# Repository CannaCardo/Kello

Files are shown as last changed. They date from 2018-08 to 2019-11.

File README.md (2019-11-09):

# Kello
> A simple USB powered Nixie Clock




USB powered clock made on four classic Z567M Nixie tubes. Pretty simplistic, without unnecessary gadgets: displays time, can be set up both from PC app or via optional capacitive buttons. Refresh frequency, brightness, time format, time and date (for adjusting winter/ summer time) can be configured as needed. Settings and current time are stored in EEprom and RTC. If the clock is connected to the PC it will update its time every minute (using the provided link).

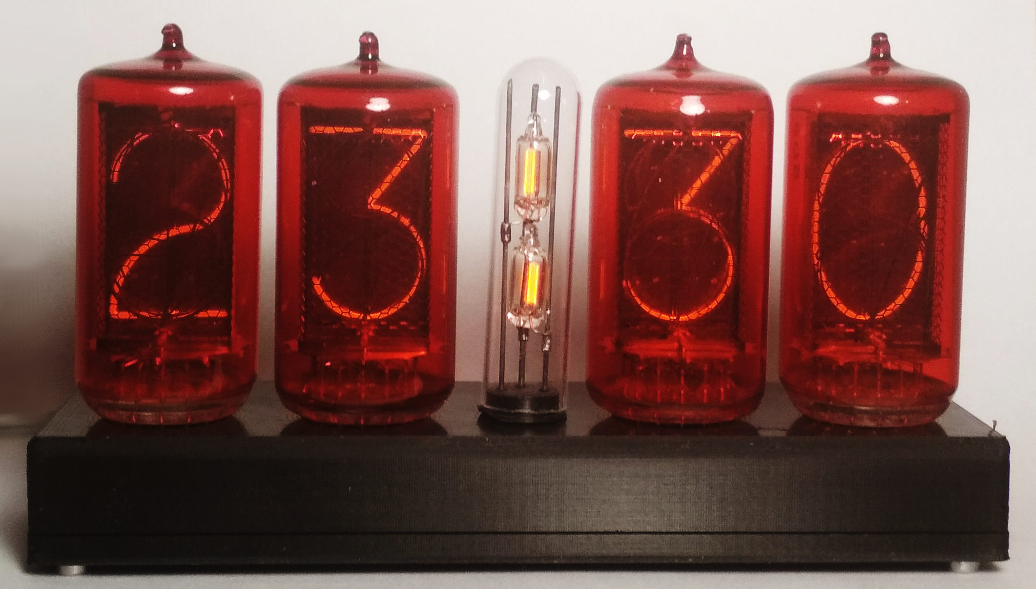
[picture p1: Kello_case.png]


For the prototype version I've dropped the idea of capacitive buttons integrated into the case, as the clock will stay connected to the PC and it's much more ergonomic to use the app.
The first idea for the clock opted for bluetooth/wifi integration, so that a smartphone could be used as interface for quick setup and the clock itself could synchronize time via Internet.  Since there already is a USB socket used to power the device it seemed silly not to connect it to the PC, which itself simplified the project rendering Wifi and BT pointless. 

## Construction advices

The Nixie standoffs can be made from D-Sub connectors (such as MH CONNECTORS MHDD25-F-T-B-M). They are pricey, but work wonders and look good. For this clock i used 3 connectors, and ended up with some leftover pins. To extract them from the socket itself cut the metal enclosure to release the black plastic holding the pins.

The dots (Neon bulbs) are soldered on 3 pieces of 2mm piano wire. Sanding the wire down before soldering will ease the process. 




## Release History

* 0.1.0
    * First Prototype
* 0.1.1
    * Placed GND Pour keepout under L1
    * Fixed RTC reseting at powerup

## Meta

Krzysztof Belewicz – belewicz@gmail.com

Distributed under the Beerware license. If you decide to build your own feel free to send me a pic.

[https://github.com/CannaCardo/github-link](https://github.com/CannaCardo/)

<!-- Markdown link & img dfn's -->
[Ver-image]: https://img.shields.io/badge/Version-1.0-orange.svg?longCache=true&style=flat-square
[Stat-image]: https://img.shields.io/badge/Status-Finished-green.svg?longCache=true&style=flat-square
[wiki]: https://github.com/CannaCardo/Kello/wiki

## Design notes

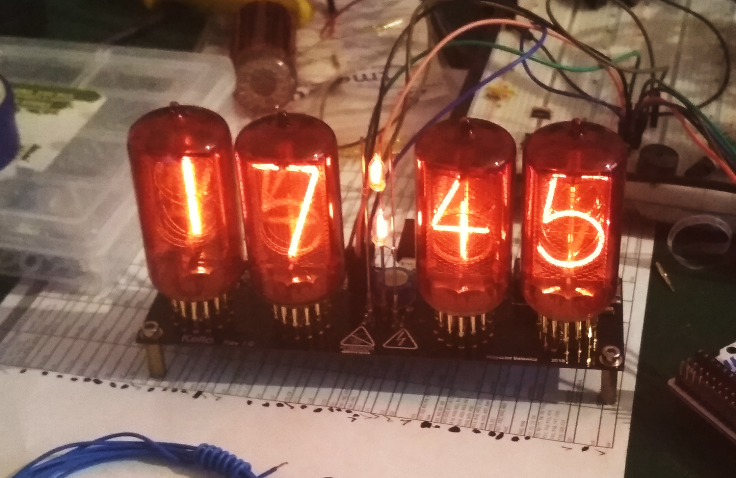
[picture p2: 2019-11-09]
Kello_bare.png

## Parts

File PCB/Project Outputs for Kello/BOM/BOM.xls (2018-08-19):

Designator | Comment | Value | Tolerance | MaxVoltage | Quantity | Supplier 1 | Supplier Part Number 1 | Manufacturer 1 | Manufacturer Part Number 1
V1, V2, V3, V4 | Z566M Nixie Tube |  |  |  | 4
C30, C31, C32, C33, P2, R47, SCR1, SCR2, SCR3, SCR4, SPCR1, SPCR2, SPCR3, SPCR4 | Capacitor, Header 1x5, Resistor, M3 Screw, M3 Spacer | DNP, [NoParam], NC | [NoValue], [NoParam], 1% |  | 14
C2 | Capacitor | 470n | 10% | 10V | 1 | Farnell | 2524844 (https://octopart-clicks.com/click/altium?sku=2524844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) | WALSIN (https://octopart-clicks.com/click/altium?sku=2524844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) | 0603B474K100CT (https://octopart-clicks.com/click/altium?sku=2524844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)
C16, C18 | Capacitor | 100u | 20% | 10V | 2 | Farnell | 2525204 (https://octopart-clicks.com/click/altium?sku=2525204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) | TDK (https://octopart-clicks.com/click/altium?sku=2525204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) | C4532X5R1A107M280KC (https://octopart-clicks.com/click/altium?sku=2525204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)
C19 | Capacitor | 100p | 5% | 250V | 1 | Farnell | 2812519 (https://octopart-clicks.com/click/altium?sku=2812519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) | WURTH ELEKTRONIK (https://octopart-clicks.com/click/altium?sku=2812519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) | 885342006003 (https://octopart-clicks.com/click/altium?sku=2812519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)
C20, C21 | Capacitor | 1u | 10% | 250V | 2 | Farnell | 2435499 (https://octopart-clicks.com/click/altium?sku=2435499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) | TDK (https://octopart-clicks.com/click/altium?sku=2435499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) | CGA8P3X7T2E105K250KA (https://octopart-clicks.com/click/altium?sku=2435499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)
C22, C23 | Capacitor | 100n | 10% | 250V | 2 | Farnell | 2852360 (https://octopart-clicks.com/click/altium?sku=2852360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) | KEMET (https://octopart-clicks.com/click/altium?sku=2852360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) | C1206C104KARECAUTO (https://octopart-clicks.com/click/altium?sku=2852360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)
C24 | Capacitor | 560p | 5% | 250V | 1 | Farnell | 2810275 (https://octopart-clicks.com/click/altium?sku=2810275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) | KEMET (https://octopart-clicks.com/click/altium?sku=2810275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) | C0603C561JAGACAUTO (https://octopart-clicks.com/click/altium?sku=2810275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)
C26 | Capacitor | 430p | 5% | 50V | 1 | Farnell | 2821196 (https://octopart-clicks.com/click/altium?sku=2821196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) | KEMET (https://octopart-clicks.com/click/altium?sku=2821196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) | C0603C431J5GACTU (https://octopart-clicks.com/click/altium?sku=2821196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)
C27 | Capacitor | 47u | 20% | 16V | 1 | Farnell | 1838761 (https://octopart-clicks.com/click/altium?sku=1838761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) | KEMET (https://octopart-clicks.com/click/altium?sku=1838761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) | C1210C476M4PACTU (https://octopart-clicks.com/click/altium?sku=1838761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)
D1, D3 | BAT54 |  |  |  | 2 | Farnell | 2322476
L1 | 7447709330 | 33uH | 20% |  | 1 | Farnell | 2082654 (https://octopart-clicks.com/click/altium?sku=2082654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) | WURTH ELEKTRONIK (https://octopart-clicks.com/click/altium?sku=2082654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) | 7447709330 (https://octopart-clicks.com/click/altium?sku=2082654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)
R38 | Resistor | 634k | 1% |  | 1 | Farnell | 2139670 (https://octopart-clicks.com/click/altium?sku=2139670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) | VISHAY (https://octopart-clicks.com/click/altium?sku=2139670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) | CRCW1206634KFKEA. (https://octopart-clicks.com/click/altium?sku=2139670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)
R39 | Resistor | 4.12k | 1% |  | 1 | Farnell | 1652883 (https://octopart-clicks.com/click/altium?sku=1652883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) | VISHAY (https://octopart-clicks.com/click/altium?sku=1652883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) | CRCW06034K12FKEA (https://octopart-clicks.com/click/altium?sku=1652883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)
R40 | Resistor | 7.68k | 1% |  | 1 | Farnell | 2307849 (https://octopart-clicks.com/click/altium?sku=2307849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) | PANASONIC (https://octopart-clicks.com/click/altium?sku=2307849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) | ERJ8ENF7681V (https://octopart-clicks.com/click/altium?sku=2307849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)
R41 | Resistor | 60.4k | 1% |  | 1 | Farnell | 2138476 (https://octopart-clicks.com/click/altium?sku=2138476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) | VISHAY (https://octopart-clicks.com/click/altium?sku=2138476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) | CRCW060360K4FKEA. (https://octopart-clicks.com/click/altium?sku=2138476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)
R46 | Resistor | 0.1 | 1% |  | 1 | Farnell | 1099914 (https://octopart-clicks.com/click/altium?sku=1099914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) | WELWYN (https://octopart-clicks.com/click/altium?sku=1099914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) | LR1206-R10FW (https://octopart-clicks.com/click/altium?sku=1099914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)
U2 | ECMF02-4CMX8 |  |  |  | 1 | Farnell | 2629721
U5 | UCC3803 |  |  |  | 1 | Farnell | 2323690 (https://octopart-clicks.com/click/altium?sku=2323690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) | TEXAS INSTRUMENTS (https://octopart-clicks.com/click/altium?sku=2323690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) | UCC3803D (https://octopart-clicks.com/click/altium?sku=2323690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)
C1, C3, C7, C9, C10, C12, C13, C14, C15, C17, C25 | Capacitor | 100n | -20/+80% | 25V | 11 | TME | CL10F104ZA8NNNC (https://octopart-clicks.com/click/altium?sku=CL10F104ZA8NNNC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) | SAMSUNG (https://octopart-clicks.com/click/altium?sku=CL10F104ZA8NNNC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) | CL10F104ZA8NNNC (https://octopart-clicks.com/click/altium?sku=CL10F104ZA8NNNC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)
C4 | Capacitor | 47n | 10% | 16V | 1 | TME | VJ0603Y473KXJCW1BC (https://octopart-clicks.com/click/altium?sku=VJ0603Y473KXJCW1BC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) | VISHAY (https://octopart-clicks.com/click/altium?sku=VJ0603Y473KXJCW1BC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) | VJ0603Y473KXJCW1BC (https://octopart-clicks.com/click/altium?sku=VJ0603Y473KXJCW1BC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)
C5 | Capacitor | 10u | 20% | 6.3V | 1 | TME | GRM188R60J106ME47D (https://octopart-clicks.com/click/altium?sku=GRM188R60J106ME47D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) | MURATA (https://octopart-clicks.com/click/altium?sku=GRM188R60J106ME47D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) | GRM188R60J106ME47D (https://octopart-clicks.com/click/altium?sku=GRM188R60J106ME47D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)
C6, C8 | Capacitor | 1u | 10% | 25V | 2 | TME | GCM188R71E105KA64D (https://octopart-clicks.com/click/altium?sku=GCM188R71E105KA64D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) | MURATA (https://octopart-clicks.com/click/altium?sku=GCM188R71E105KA64D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) | GCM188R71E105KA64D (https://octopart-clicks.com/click/altium?sku=GCM188R71E105KA64D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)
C11 | 0.47F | 0.47F |  |  | 1 | TME | FGH0V474ZF (https://octopart-clicks.com/click/altium?sku=FGH0V474ZF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) | KEMET (https://octopart-clicks.com/click/altium?sku=FGH0V474ZF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) | FGH0V474ZF (https://octopart-clicks.com/click/altium?sku=FGH0V474ZF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)
C28 | Capacitor | 1n | 10% | 50V | 1 | TME | VJ0603Y102KXACW1BC (https://octopart-clicks.com/click/altium?sku=VJ0603Y102KXACW1BC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) | VISHAY (https://octopart-clicks.com/click/altium?sku=VJ0603Y102KXACW1BC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) | VJ0603Y102KXACW1BC (https://octopart-clicks.com/click/altium?sku=VJ0603Y102KXACW1BC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)
C29 | Capacitor | 220p | 10% | 50V | 1 | TME | VJ0603Y221KXACW1BC (https://octopart-clicks.com/click/altium?sku=VJ0603Y221KXACW1BC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) | VISHAY (https://octopart-clicks.com/click/altium?sku=VJ0603Y221KXACW1BC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) | VJ0603Y221KXACW1BC (https://octopart-clicks.com/click/altium?sku=VJ0603Y221KXACW1BC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)
D2 | ES1D |  |  |  | 1 | TME | ES1D
FB1, FB2, FB3 | Ferrite Bead | 120@100MHz |  |  | 3 | TME | BLM18KG121TN1D
FB4, FB5 | Ferrite Bead | 60@100MHz |  |  | 2 | TME | BLM18BB600SN1D (https://octopart-clicks.com/click/altium?sku=BLM18BB600SN1D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) | MURATA (https://octopart-clicks.com/click/altium?sku=BLM18BB600SN1D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) | BLM18BB600SN1D (https://octopart-clicks.com/click/altium?sku=BLM18BB600SN1D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)
N1 | NEON |  |  |  | 1 | TME | NEON-9
P1 | MicroUSB-B |  |  |  | 1 | TME | MX-47346-0001 (https://octopart-clicks.com/click/altium?sku=MX-47346-0001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) | MOLEX (https://octopart-clicks.com/click/altium?sku=MX-47346-0001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) | 473460001 (https://octopart-clicks.com/click/altium?sku=MX-47346-0001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)
Q1 | Crystal 2 pin | 32.768 kHz |  |  | 1 | TME | IL3X2-HX5F12.5-32.768KHZ (https://octopart-clicks.com/click/altium?sku=IL3X2-HX5F12.5-32.768KHZ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) | ILSI (https://octopart-clicks.com/click/altium?sku=IL3X2-HX5F12.5-32.768KHZ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) | IL3X2-HX5F12.5-32.768KHZ (https://octopart-clicks.com/click/altium?sku=IL3X2-HX5F12.5-32.768KHZ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)
Q2 | 24Mhz | 24 Mhz |  |  | 1 | TME | 3225-24M-SR (https://octopart-clicks.com/click/altium?sku=3225-24M-SR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) | SR PASSIVES (https://octopart-clicks.com/click/altium?sku=3225-24M-SR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) | 3225-24M-SR (https://octopart-clicks.com/click/altium?sku=3225-24M-SR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)
Q3 | FDS2672 |  |  |  | 1 | TME | FDS2672 (https://octopart-clicks.com/click/altium?sku=FDS2672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) | ON SEMICONDUCTOR (FAIRCHILD) (https://octopart-clicks.com/click/altium?sku=FDS2672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) | FDS2672 (https://octopart-clicks.com/click/altium?sku=FDS2672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)
R1, R2, R3, R4, R36, R44 | Resistor | 100k | 1% |  | 6 | TME | CRCW0603100KFKEA (https://octopart-clicks.com/click/altium?sku=CRCW0603100KFKEA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) | VISHAY (https://octopart-clicks.com/click/altium?sku=CRCW0603100KFKEA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) | CRCW0603100KFKEA (https://octopart-clicks.com/click/altium?sku=CRCW0603100KFKEA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)
R5, R6, R7, R8 | Resistor | 430k | 1% |  | 4 | TME | SMD0603-430k
R9, R10, R11, R12, R17, R18, R19, R22, R23, R24, R25, R26, R27, R28, R29, R30 | Resistor | 33k | 1% |  | 16 | TME | SMD0603-33k
R13, R14, R15, R16, R34, R35, R37, R49 | Resistor | 2k | 1% |  | 8 | TME | SMD0603-2K-1% (https://octopart-clicks.com/click/altium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) | ROYAL OHM (https://octopart-clicks.com/click/altium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) | 0603SAF2001T5E (https://octopart-clicks.com/click/altium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)
R20, R21 | Resistor | 220k | 1% |  | 2 | TME | SMD0603-220k
R31, R32, R33, R43, R45 | Resistor | 1k | 1% |  | 5 | TME | SMD0603-1K-1% (https://octopart-clicks.com/click/altium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) | ROYAL OHM (https://octopart-clicks.com/click/altium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) | 0603SAF1001T5E (https://octopart-clicks.com/click/altium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)
R42, R48 | Resistor | 0 | 1% |  | 2 | TME | CRCW06030000Z0TABC (https://octopart-clicks.com/click/altium?sku=CRCW06030000Z0TABC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) | VISHAY (https://octopart-clicks.com/click/altium?sku=CRCW06030000Z0TABC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) | CRCW06030000Z0TABC (https://octopart-clicks.com/click/altium?sku=CRCW06030000Z0TABC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)
T1, T2, T3, T4 | MMBTA92 |  |  |  | 4 | TME | MMBTA92
T5, T6, T7, T8, T9, T10, T11, T12, T13, T14, T15, T16, T17, T18, T19, T20, T21 | MMBTA42 |  |  |  | 17 | TME | MMBTA42LT1G
U1 | STM32F042C6U6 |  |  |  | 1 | TME | STM32F042C6U6
U3 | LD1117AV33 |  |  |  | 1 | TME | LD1117AS33 (https://octopart-clicks.com/click/altium?sku=LD1117AS33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) | ST MICROELECTRONICS (https://octopart-clicks.com/click/altium?sku=LD1117AS33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) | LD1117AS33TR (https://octopart-clicks.com/click/altium?sku=LD1117AS33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)
U4 | AT24C04D |  |  |  | 1 | TME | AT24C04D-MAHM-T (https://octopart-clicks.com/click/altium?sku=AT24C04D-MAHM-T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) | MICROCHIP (https://octopart-clicks.com/click/altium?sku=AT24C04D-MAHM-T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) | AT24C04D-MAHM-T (https://octopart-clicks.com/click/altium?sku=AT24C04D-MAHM-T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)

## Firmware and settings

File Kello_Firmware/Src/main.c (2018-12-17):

/**
  ******************************************************************************
  * @file           : main.c
  * @brief          : Main program body
  ******************************************************************************
  * This notice applies to any and all portions of this file
  * that are not between comment pairs USER CODE BEGIN and
  * USER CODE END. Other portions of this file, whether 
  * inserted by the user or by software development tools
  * are owned by their respective copyright owners.
  *
  * Copyright (c) 2018 STMicroelectronics International N.V. 
  * All rights reserved.
  *
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
  ******************************************************************************
  */
/* Includes ------------------------------------------------------------------*/
#include "main.h"
#include "stm32l4xx_hal.h"
#include "usb_device.h"

/* USER CODE BEGIN Includes */
//#include "usbd_cdc_if.h" // USB
#include "EEprom.h"
#include "Display.h"
#include "Defines.h"
#include "USB.h"
/* USER CODE END Includes */

ADC_HandleTypeDef hadc1;

I2C_HandleTypeDef hi2c1;

RTC_HandleTypeDef hrtc;

TIM_HandleTypeDef htim1;
TIM_HandleTypeDef htim2;
DMA_HandleTypeDef hdma_tim2_ch3;
DMA_HandleTypeDef hdma_tim2_ch2_ch4;

/* USER CODE BEGIN PV */
HAL_StatusTypeDef DisplayStatus;
HAL_StatusTypeDef EEpromStatus;
/* USER CODE END PV */

void SystemClock_Config(void);
static void MX_GPIO_Init(void);
static void MX_DMA_Init(void);
static void MX_ADC1_Init(void);
static void MX_I2C1_Init(void);
static void MX_RTC_Init(void);
static void MX_TIM1_Init(void);
static void MX_TIM2_Init(void);

void HAL_TIM_MspPostInit(TIM_HandleTypeDef *htim);
                                

/* USER CODE BEGIN PFP */

/* USER CODE END PFP */

/**
  * @brief  The application entry point.
  *
  * @retval None
  */
int main(void)
{
  /* USER CODE BEGIN 1 */
  DisplayStatus = HAL_OK;
  EEpromStatus 	= HAL_OK;
  /* USER CODE END 1 */

  /* MCU Configuration----------------------------------------------------------*/

  /* Reset of all peripherals, Initializes the Flash interface and the Systick. */
  HAL_Init();

  /* Configure the system clock */
  SystemClock_Config();

  /* Initialize all configured peripherals */
  MX_GPIO_Init();
  MX_DMA_Init();
  MX_ADC1_Init();
  MX_I2C1_Init();
  MX_RTC_Init();
  MX_TIM1_Init();
  MX_TIM2_Init();
  MX_USB_DEVICE_Init();
  /* USER CODE BEGIN 2 */

  // Initialize settings
  EEpromStatus |= EEprom_Init();

  // Start HV Display
  DisplayStatus |= Display_Init( &htim1, &htim2 );
  Display_Set_Brightness( 	EEprom_Get_Brightness()  );
  Display_Set_RefreshRate( 	EEprom_Get_RefreshRate() );
  Display_Set_TimeFormat( 	EEprom_Get_TimeFormat()  );
  Display_Set_DotStyle(		EEprom_Get_DotStyle()	 );
  Display_Set_DotCustom( 	EEprom_Get_DotCustom() 	 );
  Display_Start();

  USB_Init();

  /* USER CODE END 2 */

  /* Infinite loop */
  /* USER CODE BEGIN WHILE */
  uint8_t OldSec = Display_Get_SL();
  while (1)
  {
  /* USER CODE END WHILE */

  /* USER CODE BEGIN 3 */
	  // React to incoming requests
	  if( USB_RX_IsReceived() ) USB_RX_Respond();

	  // Wait for a second
	  if( OldSec == Display_Get_SL() ) continue;
	  OldSec = Display_Get_SL();

	  //USB_TX_Info();
  }
  /* USER CODE END 3 */

}

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


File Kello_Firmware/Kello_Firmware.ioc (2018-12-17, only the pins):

Mcu.UserName=STM32L433CBUx
PA10.GPIO_Label=EE_SDA
PA10.Signal=I2C1_SDA
PA11.Signal=USB_DM
PA12.Signal=USB_DP
PA8.GPIO_Label=EE_WP
PA8.Signal=GPIO_Output
PA9.GPIO_Label=EE_SCL
PA9.Signal=I2C1_SCL
PB10.GPIO_Label=DOT_L
PB10.Signal=S_TIM2_CH3
PB11.GPIO_Label=DOT_H
PB11.Signal=S_TIM2_CH4
PB12.GPIO_Label=Anode_4
PB12.Signal=GPIO_Output
PB13.GPIO_Label=Anode_3
PB13.Signal=GPIO_Output
PB14.GPIO_Label=Anode_2
PB14.Signal=GPIO_Output
PB15.GPIO_Label=Anode_1
PB15.Signal=GPIO_Output
PB2.GPIO_Label=HV_Enable
PB2.Signal=GPIO_Output
PB5.GPIO_Label=Digit_8
PB5.Signal=GPIO_Output
PB6.GPIO_Label=Digit_7
PB6.Signal=GPIO_Output
PB7.GPIO_Label=Digit_6
PB7.Signal=GPIO_Output
PB8.GPIO_Label=Digit_4
PB8.Signal=GPIO_Output
PB9.GPIO_Label=Digit_2
PB9.Signal=GPIO_Output
PC13.GPIO_Label=Digit_3
PC13.Signal=GPIO_Output
PH3-BOOT0.GPIO_Label=Digit_5
PH3-BOOT0.Signal=GPIO_Output

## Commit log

2018-04-01 Schematics 1
    Added Nixie page (finished)
    Added Mechanical page
    Added uC page
    [Kello.PrjPCB, Kello_Mechanical.SchDoc, Kello_Nixie.SchDoc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]
2018-05-07 Finished schematic
    [Kello.PrjPCB, Kello_Mechanical.SchDoc, Kello_Nixie.SchDoc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]
2018-08-19 Prototype done
    -1.0 Prototype done
    -Basic Firmware written
    [BOM.xls, Kello.PrjPCB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]
2018-12-17 Firmware finished, uC changed to STM32L433CBUx
    [BOM.xls, Kello.PrjPCB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]

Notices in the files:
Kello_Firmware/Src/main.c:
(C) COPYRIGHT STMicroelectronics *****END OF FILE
